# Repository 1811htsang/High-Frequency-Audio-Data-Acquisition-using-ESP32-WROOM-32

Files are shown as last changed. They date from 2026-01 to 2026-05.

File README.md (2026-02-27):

# High-Frequency-Audio-Data-Acquisition-using-ESP32-WROOM-32

## Introduction

Design and implementation of a high-frequency audio data acquisition system using the ESP32-WROOM-32 microcontroller. The project aims to capture and process audio signals in real-time, leveraging the capabilities of the ESP32 for efficient data handling and transmission for audio tasks such as recording and playback.

---

## Structure

- `docs/`: Documentation and design notes.
  - `notes/`: Development notes and considerations.
  - `references/`: Reference materials and datasheets.
- `project-architecture/`: Overview of the project architecture, containing main driver code structure.
- `project-kicadspace/`: KiCad design files for the PCB layout and schematic.
- `project-obsidianspace/`: Obsidian vault for project notes and documentation.

---

## Overview

This project focuses on the development of a high-frequency audio data acquisition system using the ESP32-WROOM-32 microcontroller. The system is designed to capture audio signals at high sampling rates, process the data in real-time, and transmit it for further analysis or storage. The project encompasses both hardware design, including PCB layout and component selection, and software development for efficient data handling and communication. Key features include:

- Real-time audio data acquisition and processing.
- Efficient data transmission using the ESP32's Wi-Fi, Bluetooth & external storage capabilities.
- Robust firmware design for reliable operation in various conditions.

---

## Features

- **Microcontroller**: ESP32-S3-DevKitC N16R8 for high-performance processing and connectivity.
- **Peripherals**:
  - SPI for communication with external microSD card for data storage
  - I2S for audio data acquisition from the ADC
  - GPIO for status indicators and control signals
  - RCC for reset & clock management
  - IWDG for watchdog functionality
  - I2C for LCD interfacing (optional)
  - DMA for efficient data transfer from ADC to memory

---

## Hardware Components

Note that this sections can be expand with new requirements in the future.

- ESP32-WROOM-32 microcontroller
- MAX9812 microphone amplifier
- PCM1808 ADC
- TL072IDT operational amplifier
- MicroSD card module for data storage
- Optional: I2C LCD display for status monitoring

---

## References

- Audio Data Acquisition System Design Based on ARM and DSP by Yongxin Wang, 2015.

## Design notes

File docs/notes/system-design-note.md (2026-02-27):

# Ghi chú về thiết kế hệ thống

## Giới thiệu

Ghi chú này tổng hợp các thiết kế hệ thống của dự án nhằm đảm bảo hoạt động ổn định và hiệu quả.

## Ý tưởng thiết kế

Thiết kế sử dụng sẽ lấy ý tưởng từ tài liệu [paper](../references/audio-data-acquisition-system-design-based-on-arm-and-dsp.pdf) nhằm đảm bảo tính ổn định và hiệu quả của hệ thống đã được kiểm chứng.

Đối với thiết kế hệ thống của tài liệu, nhóm tác giả sử dụng kết hợp giữa 1 vi điều khiển ARM với 1 DSP để xử lý âm thanh phức tạp.

Do đó, một câu hỏi đặt ra là ta có thể sử dụng một vi điều khiển duy nhất với 1 bộ thu thập dữ liệu sử dụng MAX9812, PCM1808, TL072IDT để thay thế cho thiết kế ban đầu hay không?

## Thay đổi thiết kế tương ứng

Từ thiết kế ban đầu, đã có một số thay đổi để phù hợp với yêu cầu của dự án:

- Thay thế cấu trúc thiết kế hệ thống của bài báo bằng một thiết kế mới sử dụng ESP32-S3-DevKitC N16R8 làm vi điều khiển chính, kết hợp với các bộ thu thập dữ liệu như MAX9812, PCM1808, TL072IDT để xử lý âm thanh.
- Vận dụng các giao thức như SPI, I2S, GPIO, RCC, IWDG, I2C và DMA để đảm bảo hiệu quả trong việc thu thập và xử lý dữ liệu âm thanh tương tự (96kHz/24-bit) như trong thiết kế ban đầu.

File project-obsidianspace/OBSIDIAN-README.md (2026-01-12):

# High-Frequency-Audio-Data-Acquisition-using-ESP32-WROOM-32
This README is a sub-artifact served as an inner README or artifactspace of the main project (parent folder).

## obsidianspace contents
The obsidianspace of the project **High-Frequency-Audio-Data-Acquisition-using-ESP32-WROOM-32** contains input sources from [docs](/docs/) of the main project.

Below is short explanation of the folder structure in the obsidianspace.

```
├── references
```

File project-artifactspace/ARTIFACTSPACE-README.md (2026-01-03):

# High-Frequency Audio Data Acquisition using ESP32-WROOM-32
This README is a sub-artifact served as an inner README or artifactspace of the main project (parent folder).

## artifactspace contents
The artifactspace of the project **High-Frequency Audio Data Acquisition using ESP32-WROOM-32** contains one source file in C language [main.c](main/main.c). The file is located in folder [main](main).

ESP-IDF projects are built using CMake. The project build configuration is contained in `CMakeLists.txt` files that provide set of directives and instructions describing the project's source files and targets (executable, library, or both). 
Below is short explanation of remaining files in the project folder.

```
├── CMakeLists.txt
├── main
│   ├── CMakeLists.txt
│   └── main.c
└── README.md                  This is the file you are currently reading
```
Additionally, the sample project contains Makefile and component.mk files, used for the legacy Make based build system. 
They are not used or needed when building with CMake and idf.py.

## Additional information
The ESP32-WROOM-32 is in fact the ESP32-DOWDQ6 denoted on [ESP32 Series Datasheet](docs\references\esp32-series-datasheet-ver-4_7.pdf)

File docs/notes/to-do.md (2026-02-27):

# To do List

## Ghi chú

Lộ trình triển khai chi tiết, đi từ

  1. **Cốt lõi** (Hardware interface & I2S Driver)
  2. **Kiến trúc** (Dual-core & Memory Management)
  3. **DSP** (Digital Signal Processing)
  4. **Giao tiếp dữ liệu** (Connectivity & Data Visualization)
  5. **Kiểm chứng và tối ưu** (Validation & Optimization)

## Giai đoạn Cốt lõi

- [x] Thiết kế khung dự án (Project Structure)
- [x] Bổ sung các tài liệu căn bản của dự án
- [x] Tìm hiểu về thiết kế reset và clock nội bộ của ESP32
- [x] Viết driver setup clock cho ESP32 lên tối đa 240MHz
- [x] Tìm hiểu về I2S Protocol và cách hoạt động của I2S trên ESP32
- [x] Tìm hiểu các linh kiện phần cứng hỗ trợ thiết kế
- [x] Tìm hiểu về SPI Protocol và cách hoạt động của SPI trên ESP32
- [x] Tái cấu trúc và thay đổi cách tận dụng driver từ ESP-IDF thay thế cho bare-metal driver
- [x] Mua linh kiện phần cứng cần thiết cho việc phát triển và thử nghiệm

## Giai đoạn Kiến trúc

## Giai đoạn DSP

## Giai đoạn Giao tiếp dữ liệu

## Giai đoạn Kiểm chứng và tối ưu

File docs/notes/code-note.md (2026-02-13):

# Ghi chú khi viết driver cho ESP32

## Các lưu ý quan trọng

1. Trước khi viết driver nên tìm hiểu bổ sung về vấn đề Big/Little Endian trên ESP32. Nếu không xác định đúng sẽ rất dễ gặp lỗi khi xử lý dữ liệu nhị phân hoặc trong quá trình cài đặt thanh ghi hoặc set/reset các bit trên thanh ghi sẽ bị sai lệch.
2. Nên thiết kế driver theo 3 lớp, trong đó:

   - Lớp thấp nhất: Giao tiếp trực tiếp với phần cứng (thanh ghi, bus giao tiếp,...)
   - Lớp trung gian: Xử lý các logic nghiệp vụ, chuyển đổi dữ liệu giữa lớp thấp và lớp cao.
   - Lớp cao nhất: Cung cấp API cho ứng dụng sử dụng driver.

    Phương pháp này giúp tách biệt rõ ràng các chức năng, dễ dàng bảo trì và mở rộng trong tương lai. Ngoài ra, hỗ trợ kiểm tra unit test cho từng lớp riêng biệt.

3. Sử dụng các macro và định nghĩa trong file lib_keyword_define.h để đảm bảo tính nhất quán và dễ bảo trì mã nguồn.

## Ghi chú ngày 12-2-2026

Dựa trên các đánh giá về việc khai thác hướng xây dựng driver bare-metal cho ESP32, đối với dự án này sẽ thực hiện việc sử dụng ESP-IDF framework để tận dụng các thư viện và công cụ hỗ trợ sẵn có. Điều này giúp giảm thiểu thời gian phát triển và tăng tính ổn định của hệ thống.

Nguyên nhân được đưa ra như sau:

- Kiến trúc của ESP32 theo hướng SoC với nhiều thành phần tích hợp sẵn, việc viết driver từ đầu sẽ rất phức tạp và dễ gặp lỗi so với STM32 là 1 MCU.
- ESP-IDF cung cấp nhiều driver và thư viện đã được tối ưu hóa, giúp tiết kiệm thời gian phát triển.
- Việc sử dụng ESP-IDF giúp tận dụng cộng đồng hỗ trợ rộng lớn và tài liệu phong phú, giúp giải quyết các vấn đề nhanh hơn.

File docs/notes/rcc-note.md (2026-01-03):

# Reset
Chia ra làm 3 loại:
- CPU reset
- Core reset
- System reset

## CPU reset
Chỉ thực hiện reset các reg của lõi CPU

## Core reset
Thực hiện reset tất cả thanh ghi trừ nhóm thanh ghi RTC

## System reset
Thực hiện reset tất cả thanh ghi (kể cả nhóm thanh ghi RTC) về giá trị mặc định.

### Nhận xét
System reset là loại reset cao nhất, do đó việc lựa chọn reset cần phải cân nhắc kỹ lưỡng để tránh việc reset không cần thiết. Ngoài ra, tất cả các loại reset đều không ảnh hưởng đến RAM. 

## Nguồn reset
Do CPU chia ra APP_CPU và PRO_CPU nên có 2 nguồn reset riêng biệt:
- Nguồn reset của PRO_CPU trữ trong thanh ghi `RTC_CNTL_RESET_CAUSE_PROCPU`
- Nguồn reset của APP_CPU trữ trong thanh ghi `RTC_CNTL_RESET_CAUSE_APPCPU`

Bảng tra cứu reset có trong [tech-dts](/docs/references/esp32-technical-reference-manual-ver-5_2.pdf) trang 40

## Quy trình reset sử dụng Software reset
1. `RTC_CNTL_OPTIONS0_REG->RTC_CNTL_SW_SYS_RST = 1;` // System reset

Do việc reset này bổ sung thêm việc lựa chọn cụ thể CPU cho việc reset:
- Với APP_CPU, `RTC_CNTL_RESET_STATE_REG->RTC_CNTL_RESET_CAUSE_APPCPU = 0x03;` // Software reset applies System reset to APP CPU
- Với PRO_CPU, `RTC_CNTL_RESET_STATE_REG->RTC_CNTL_RESET_CAUSE_PROCPU = 0x03;` // Software reset applies System reset to PRO CPU

## Quy trình reset sử dụng CPU reset
Đối với CPU reset, chỉ có thể reset từng CPU riêng biệt

Với APP_CPU:
1. `RTC_CNTL_OPTIONS0_REG->RTC_CNTL_SW_APPCPU_RST = 1;` // CPU reset với APP CPU
2. Với APP_CPU, `RTC_CNTL_RESET_STATE_REG->RTC_CNTL_RESET_CAUSE_APPCPU = 0x0C;` // Software reset applies System reset to APP CPU

Với PRO_CPU:
1. `RTC_CNTL_OPTIONS0_REG->RTC_CNTL_SW_PROCPU_RST = 1;` // CPU reset với PRO CPU
2. Với PRO_CPU, `RTC_CNTL_RESET_STATE_REG->RTC_CNTL_RESET_CAUSE_PROCPU = 0x0C;` // Software reset applies System reset to PRO CPU

## Trường hợp đặc biệt
Do APP_CPU được điều khiển bổ sung bởi nhóm thanh ghi DPort (PRO_CPU khong có), do đó việc reset APP_CPU có thể thực hiện thông qua DPort (`DPORT_APPCPU_CTRL_REG_A_REG->DPORT_APPCPU_RESETTING = 1;`)

Tuy nhiên cách thực hiện reset chỉ xảy ra với nguồn đầu vào là tín hiệu reset độc lập của PRO_CPU.

Kiểm chứng thông tin trong [tech-dts](/docs/references/esp32-technical-reference-manual-ver-5_2.pdf) trang 40, 41

# Clock system trên ESP32-WROOM-32
Về thiết kế cơ bản, ESP32-WROOM-32 gồm các nguồn chính sau:
- CLK tốc độ cao
  - `PLL_CLK` là clk nội bộ với dải tần số từ 320MHz đến 480MHz
  - `XTL_CLK` là clk từ thạch anh ngoài với tần số 2-40MHz
- CLK tốc độ thấp
  - `XTL32K_CLK` là clk từ thạch anh ngoài với tần số 32kHz 
  - `RC_FAST_CLK` là nguồn clock nội với tần số mặc định 8MHz có thể tùy chỉnh
  - `RC_FAST_DIV_CLK` là nguồn tách từ `RC_FAST_CLK` với phần chia 256. Do đó với tần số mặc định 8MHz thì `RC_FAST_DIV_CLK` có tần số 31.25kHz
  - `RC_SLOW_CLK` là nguồn clock nội với tần số mặc định 150kHz có thể tùy chỉnh
- CLK cho Audio
  - `APLL_CLK` là clock nội bộ dành riêng cho Audio với tần số từ 16MHz đến 128MHz

Kiểm tra nguồn thông tin trong [tech-dts](/docs/references/esp32-technical-reference-manual-ver-5_2.pdf) trang 41 đối với phần cấu trúc thiết kế hệ thống clock trên ESP32-WROOM-32

## Nguồn clock cho CPU

Ngoài các nguồn clock trên, CPU còn có nguồn clock riêng biệt là `CPU_CLK` sử dụng riêng biệt cho lõi CPU. Ở chế độ hiệu năng cao, `CPU_CLK` có thể đạt tần số tối đa 240MHz.

Việc lựa chọn nguồn clock cho `CPU_CLK` được xác định bởi thanh ghi `RTC_CNTL_SOC_CLK_SEL`. Trong đó `PLL_CLK`, `APLL_CLK`, `RC_FAST_CLK` và  `XTL_CLK` đều có thể được lựa chọn làm nguồn cho `CPU_CLK`.

Kiểm chứng thông tin trong [tech-dts](/docs/references/esp32-technical-reference-manual-ver-5_2.pdf) trang 42-43.

## Nguồn clock cho ngoại vi
Nguồn clock cho tất cả các ngoại vi được lấy đầu vào từ 5 nguồn chính là
- `APB_CLK`
- `REF_TICK`
- `LEDC_SCLK`
- `APLL_CLK`
- `PLL_F160M_CLK`

Ngoài ra, tùy thuộc vào từng ngoại vi cụ thể mà có thể sử dụng các nguồn CLK khác nhau, điều này được ghi chú kỹ trong phần mô tả [tech-dts](/docs/references/esp32-technical-reference-manual-ver-5_2.pdf) từ trang 43.

Lưu ý ở đây chỉ tập trung vào các nguồn clock chính, các nguồn clock không sử dụng trong dự án sẽ không được đề cập.

### `APB_CLK`
Nguồn này lấy từ 4 nguồn chính là `PLL_CLK`, `APLL_CLK`, `XTL_CLK` và `RC_FAST_CLK`.

Bảng thông số chia nguồn `APB_CLK` có trong [tech-dts](/docs/references/esp32-technical-reference-manual-ver-5_2.pdf) trang 43.

### `REF_TICK`
Nguồn này phụ thuộc vào `APB_CLK` mà `APB_CLK` được xác định bởi `CPU_CLK`.

Trong tài liệu, nguồn này được khuyến khích đảm bảo cố định (không ràng buộc tần số ở 1MHz). Nghĩa là khi thay đổi `CPU_CLK` thì người sử dụng nên đảm bảo nguồn `REF_TICK` vẫn giữ nguyên tần số mong muốn.

Bảng thông tin nằm trong [tech-dts](/docs/references/esp32-technical-reference-manual-ver-5_2.pdf) trang 44.

Giải thích ví dụ ở trang 44:
> Khi nguồn `CPU_CLK` là `PLL_CLK` và người dùng cần giữ `REF_TICK` ở 1MHz thì phải đảm bảo `SYSCON_PLL_TICK_NUM=0x4F` để tần số `REF_TICK` tương đương `80/(79+1)=1` (Thông tin về công thức nằm chung với bảng ở trang 44).

### `APLL_CLK` cho ngoại vi
Như đã đề cập trước đó, `APLL_CLK` là nguồn clock nội bộ dành riêng cho Audio với tần số từ 16MHz đến 128MHz.

Nguồn đầu vào chính của `APLL_CLK` là từ `PLL_CLK`, do đó phải sử dụng bổ sung các nhóm thanh ghi để điều chỉnh tần số của `APLL_CLK`. 

Tuy nhiên, trong tài liệu không đề cập rõ ràng thông tin về điều chỉnh trực tiếp tần số của `APLL_CLK` mà chỉ xem `APLL_CLK` là nguồn con phụ thuộc vào `PLL_CLK`.

Ngoài ra còn có 1 phần đề mục *Audio PLL* riêng biệt khỏi `APLL_CLK` trong tài liệu và thông tin cụ thể chi tiết hơn.

Do đó, có thể suy đoán rằng việc điều chỉnh tần số của `APLL_CLK` sẽ thông qua việc điều chỉnh tần số của `PLL_CLK`.

Kiểm chứng thông tin trong [tech-dts](/docs/references/esp32-technical-reference-manual-ver-5_2.pdf) trang 44.

### `PLL_F160M_CLK`
Nguồn này lấy trực tiếp từ `PLL_CLK` với tần số cố định 160MHz không thay đổi.

## Cân nhắc lựa chọn clock đối với ngoại vi
Trong tài liệu về bảng thông tin nguồn clock cho các loại ngoại vii, ta có thể thấy rằng tất cả ngoại vi đều có thể sử dụng `APB_CLK` làm nguồn clock chính. 

Ngoài ra nếu tần số của `APB_CLK` bị thay đổi thì các ngoại vi cũng đều phải thực hiện cập nhật lại tần số hoạt động tương ứng trừ các ngoại vi có thể sử dụng `REF_TICK` làm nguồn clock.

## Nguồn clock cho Wi-Fi và Bluetooth
Sử dụng bắt buộc nguồn clock chính là `PLL_CLK`. Nếu không sử dụng `PLL_CLK` thì cả 2 chức năng này sẽ tiến vào trạng thái hoạt động tiêu thụ thấp (low-power mode).

Nếu sử dụng trong chế độ tiết kiệm năng lượng (modem-sleep mode) thì có thể sử dụng các nguồn clock phụ là `RC_SLOW_CLK`, `RC_FAST_CLK` hoặc `XTL_CLK`.

Kiểm chứng thông tin trong [tech-dts](/docs/references/esp32-technical-reference-manual-ver-5_2.pdf) trang 45.

## Nguồn clock cho RTC
Trong thiết kế hệ thống clock của ESP32, RTC có 2 nguồn chính là `RTC_SLOW_CLK` và `RTC_FAST_CLK`, 2 nguồn này giúp cho RTC có thể hoạt động khi hầu hết các nguồn khác bị tắt.

Dựa vào thiết kế truy ngược lại, ta có thể thấy:

### RTC_FAST_CLK
Nguồn này lấy từ 2 nguồn chính là
- `RC_FAST_CLK`
- `XTL_CLK` + Bộ chia tần số -> `XTAL_DIV_CLK`

Nguồn này có thể sử dụng cho các module quản lý năng lượng.

### RTC_SLOW_CLK
Nguồn này lấy từ 3 nguồn chính là
- `RC_SLOW_CLK`
- `XTL32K_CLK`
- `RC_FAST_DIV_CLK`

Nguồn này có thể sử dụng cho các module cảm biến trên chip.

Kiểm chứng thông tin trong [tech-dts](/docs/references/esp32-technical-reference-manual-ver-5_2.pdf) trang 45.

## Nguồn clock cho Audio PLL
Công thức tính nguồn clock ra từ Audio PLL như sau:
$$\large{f_{\text{out}}=\frac{f_{\text{xtal}}(\text{sdm2}+\frac{\text{sdm1}}{2^{8}}+\frac{\text{sdm0}}{2^{16}}+4)}{2(\text{odiv}+2)}}$$

Trong đó:
- \(f_{xtal}\) là tần số của thạch anh ngoài (thường là 40MHz)
- sdm2, sdm1, sdm0 là các hệ số điều chỉnh tần số
  - sdm2 là phần nguyên lấy giá trị từ 0 đến 63
  - sdm1 là phần phân số lấy giá trị từ 0 đến 255
  - sdm0 là phần phân số lấy giá trị từ 0 đến 255
- odiv là hệ số chia tần số đầu ra, giá trị từ 0 đến 31

Với công thức này, toán hạng tử số có thể đạt từ 350MHz đến 500MHz.

Ngoài ra, cần chú ý rằng ở revision0 của ESP32, không thể setup `smd0` và `smd1`, kiểm chứng thông tin trong [soc-errata](../references/esp32-eco-&-workarounds-for-bugs-ver-2_3.pdf) trang 12.

Audio PLL có thể được điều khiển thủ công qua thanh ghi `RTC_CNTL_PLLA_FORCE_PU` và `RTC_CNTL_PLLA _FORCE_PD` tương ứng. Quyền vô hiệu hóa có mức ưu tiên cao hơn so với quyền kích hoạt. Nếu cả 2 thanh ghi đều là 0 thì Audio PLL sẽ tuân thủ theo trạng thái hoạt động của hệ thống.

## Quy trình setup Clock cho ESP32
Dựa trên các nguồn thông tin đã thu thập, các hạng mục chính cần setup clock bao gồm `CPU_CLK`, `REF_TICK`.

### Setup `CPU_CLK`
1. Chọn nguồn clock cho CPU trong `RTC_CNTL_SOC_CLK_SEL`. Ở đây chọn `PLL_CLK` làm nguồn chính cho CPU (Lý giải bên dưới) 
2. `RTC_CNTL_CLK_CONF_REG->RTC_CNTL_SOC_CLK_SEL=01`; // Chọn PLL_CLK làm nguồn cho CPU_CLK
3. `DPORT_CPU_PER_CONF_REG->DPORT_CPU_CPUPERIOD_SEL=10`; // Chọn tần số CPU là 240MHz

**Lý giải**:

Ở đây chọn `PLL_CLK` làm nguồn cho CPU vì
- Lấy mẫu ở tốc độ 100ksps có nghĩa là cứ 10µs hệ thống lại nhận được một mẫu dữ liệu mới. Mặc dù DMA giúp chuyển dữ liệu vào RAM mà không tốn CPU, nhưng sau đó Core 1 phải xử lý khối dữ liệu khổng lồ này (FFT, Filtering) và Core 0 phải duy trì Wifi Stack.
- Do đó, để đảm bảo hệ thống xử lý kịp thời gian thực, cần thiết lập CPU ở tần số cao nhất là 240MHz. Các nguồn khác như `XTL_CLK` hay `RC_FAST_CLK` không thể đáp ứng được tần số này.
- Ngoài ra loại bỏ việc sử dụng `APLL_CLK` làm nguồn cho CPU vì nguồn này dành riêng cho Audio, việc sử dụng nó cho CPU như đã đề cập sẽ làm gián đoạn chức năng Audio trong trường hợp tần số `APLL_CLK` bị thay đổi.

### Setup `REF_TICK`
1. Xác định tần số mong muốn cho REF_TICK (Ở đây chọn 1MHz)
2. `SYSCON_PLL_TICK_CONF_REG->SYSCON_PLL_TICK_NUM=0x4F`; // Thiết lập tần số REF_TICK là 1MHz khi CPU_CLK là PLL_CLK

> Ở đây sẽ bổ sung thêm phần setup clock cho các ngoại vi nếu cần thiết trong tương lai.

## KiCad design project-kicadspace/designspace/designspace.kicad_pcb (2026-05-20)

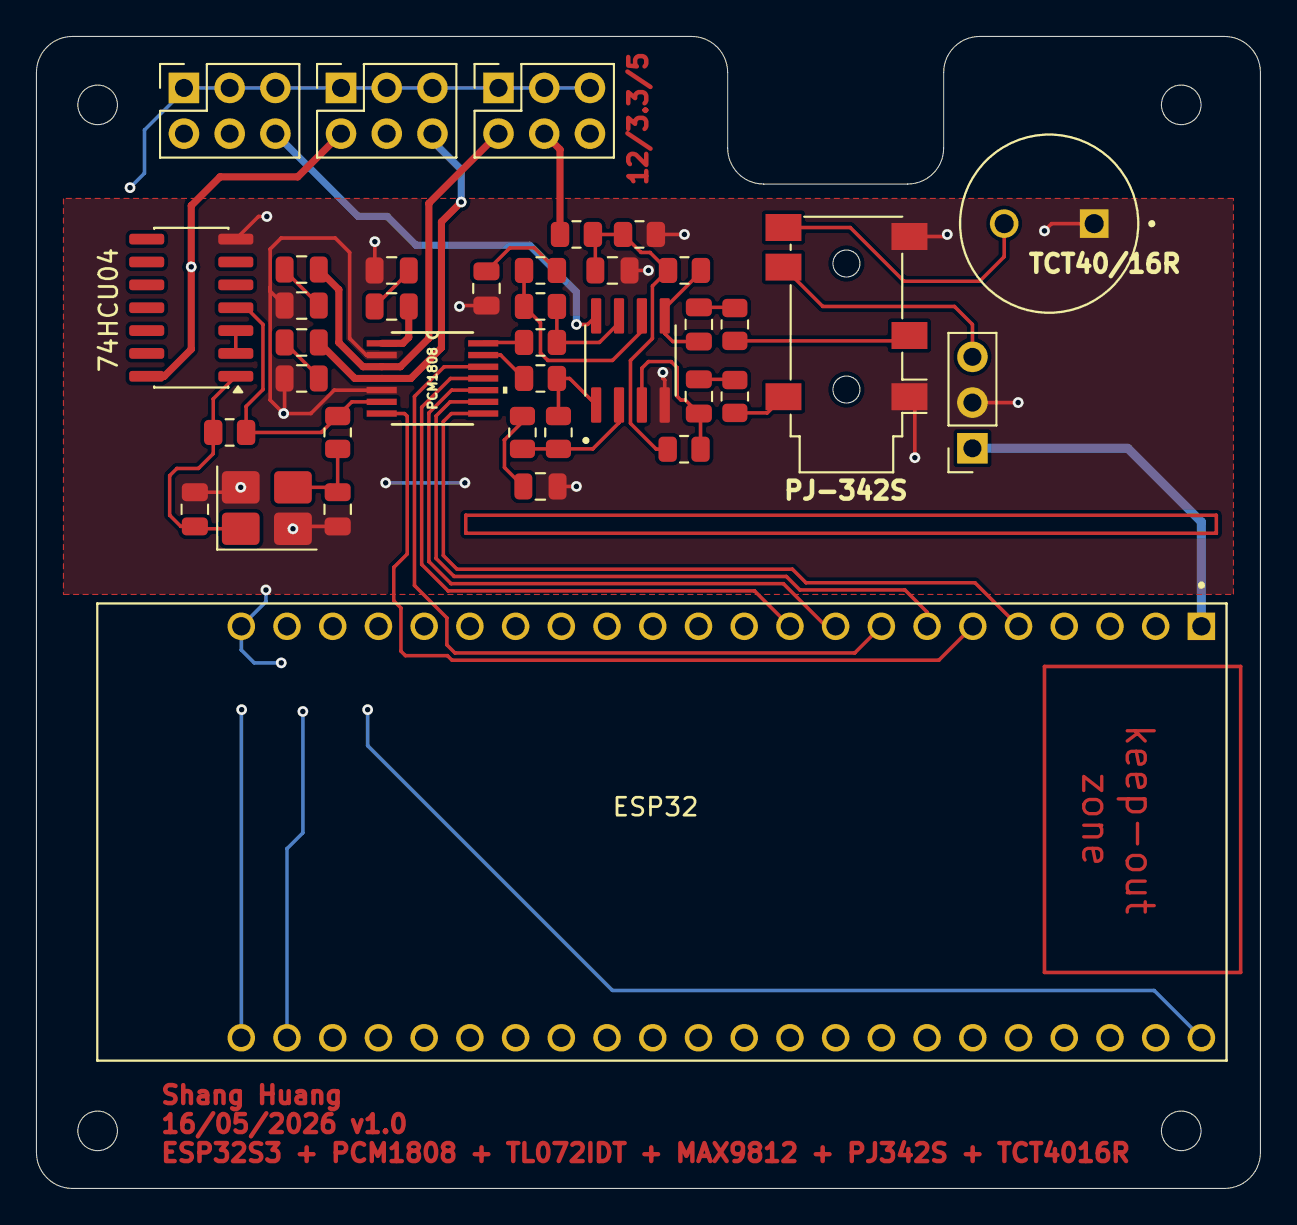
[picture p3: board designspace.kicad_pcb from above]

Board: 2 copper layers, 68.0 x 64.0 mm, 34 parts (0 on the bottom side), 33 nets.

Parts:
C3, C15: 1uF; C_0805_2012Metric
C4, C6, C8, C10, C13, C14: 10uF; C_0805_2012Metric
C5, C7, C9: 0.1uF; C_0805_2012Metric
C11, C12: 27pF; C_0805_2012Metric
ESP32: ESP32-S3-DEVKITC-1-N8R8
INVBUF1: 74HCU04; SO-14_3.9x8.65mm_P1.27mm
J1: PJ-313B; pj342s audio jack
MK2: TCT40-16R
Op-amp2: TL072; TL072IDT
Osc1: 24.576MHz; Crystal_SMD_3225-4Pin_3.2x2.5mm_HandSoldering
PCM1808: PCM1808PWR; PW14
R2, R3, R4, R10, R11: 10kOhm; R_0805_2012Metric
R5, R6, R9, R15: 1kOhm; R_0805_2012Metric
R7, R13: 100kOhm; R_0805_2012Metric
R8, R12: 1MOhm; R_0805_2012Metric
R14: 2.2kOhm; R_0805_2012Metric

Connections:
3.3V: C8.1, ESP32.3V3, INVBUF1.14 (VCC), PCM1808.4 (VDD)
5V: C4.1, PCM1808.3 (VCC), R2.1
GND: C5.1, C6.2, C9.1, C10.1, C11.2, C12.2, C13.1, C14.1, ESP32.GND, ESP32.GND1, ESP32.GND2, ESP32.GND3, INVBUF1.7 (GND), J1.G, J1.S, MK2.1 (-), Op-amp2.4 (V-), Osc1.2 (G), Osc1.4 (G), PCM1808.2 (AGND), PCM1808.5 (DGND), R3.2
unnamed: C3.2, R10.1
unnamed: C4.2, C5.2
unnamed: C6.1, C7.1
unnamed: C8.2, C9.2
unnamed: C10.2, R5.1
unnamed: C11.1, INVBUF1.1, Osc1.1, R8.1
unnamed: C12.1, Osc1.3, R9.1
unnamed: C13.2, R2.2, R3.1, R7.1, R12.2
unnamed: C14.2, R14.1
unnamed: C15.2, R11.1
unnamed: INVBUF1.2, INVBUF1.3
unnamed: J1.R1, R11.2
unnamed: J1.T, R10.2
unnamed: J1.R2, MK2.2 (+)
unnamed: Op-amp2.1, R4.1, R6.1
unnamed: Op-amp2.7, R13.1, R15.2
unnamed: C3.1, Op-amp2.3 (+), R7.2
unnamed: Op-amp2.2 (-), R4.2, R5.2
unnamed: C15.1, Op-amp2.5 (+), R12.1
unnamed: Op-amp2.6 (-), R13.2, R14.2
unnamed: ESP32.GPIO5, PCM1808.8 (BCK)
unnamed: ESP32.GPIO7, PCM1808.9 (DOUT)
unnamed: ESP32.GPIO15, PCM1808.12 (FMT)
unnamed: ESP32.GPIO6, PCM1808.7 (LRCK)
unnamed: ESP32.GPIO16, PCM1808.10 (MD0)
unnamed: ESP32.GPIO17, PCM1808.11 (MD1)
unnamed: INVBUF1.4, PCM1808.6 (SCKI), R8.2, R9.2
unnamed: PCM1808.13 (VINL), R6.2
unnamed: PCM1808.14 (VINR), R15.1
unnamed: C7.2, PCM1808.1 (VREF)

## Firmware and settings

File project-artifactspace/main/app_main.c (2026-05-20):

// Khai báo các thư viện sử dụng

  #include <stdio.h>
  #include <stdint.h>
  #include <inttypes.h>
  #include "esp_system.h"
  #include "soc/clk_tree_defs.h"
  #include "esp_clk_tree.h"
  #include "esp_pm.h"
  #include "esp_log.h"
  #include "freertos/FreeRTOS.h"
  #include "freertos/task.h"
  #include "driver/i2s_std.h"
  #include "driver/i2s_common.h"
  #include "driver/gpio.h"
  #include "lib_keyword_def.h"
  #include "lib_condition_def.h"

// Khai báo các hằng số và biến toàn cục nếu cần thiết

  #define LOG_LOCAL_LEVEL ESP_LOG_VERBOSE

  #define ui32 uint32_t
  #define ui16 uint16_t
  #define ui8 uint8_t

  #define I2S_SAMPLE_RATE_HZ 96000
  #define I2S_RX_BUFFER_SAMPLES 512
  #define I2S_LOG_SAMPLES_PER_CHUNK 8

// Khai báo các hàm sử dụng làm việc

  void check_reset_reason(void);
  void check_cpu_clock(void);

// Thực thi chương trình chính

  void app_main(void) {

    // Kiểm tra nguyên nhân khởi động
      
      check_reset_reason();

    // Kiểm tra xung clock nội bộ

      check_cpu_clock();

    // Cấu hình quản lý năng lượng

      /**
       * Ghi chú:
       * Đã sử dụng cấu hình năng lượng thông qua
       * `menuconfig` nên không cần dùng API để cấu hình lại ở đây
       */

    // Cấu hình I2S

      // Khởi tạo I2S channel
      i2s_chan_handle_t rx_handle;
      i2s_chan_config_t chan_cfg = I2S_CHANNEL_DEFAULT_CONFIG(I2S_NUM_0, I2S_ROLE_MASTER);
      chan_cfg.dma_desc_num = I2S_LOG_SAMPLES_PER_CHUNK;
      chan_cfg.dma_frame_num = I2S_RX_BUFFER_SAMPLES;
      ESP_ERROR_CHECK(i2s_new_channel(&chan_cfg, NULL, &rx_handle));

      // Cấu hình I2S định dạng chuẩn
      /**
       * Ghi chú:
       * Theo tài liệu Series datasheet của S3,
       * thì I2S được quyền sử dụng các chân từ GPIO4 đến GPIO7 cho chức năng I2S, 
       * ngoài ra trên thực tế, các chân này liền kề nhau 
       * cũng giúp việc routing tín hiệu dễ dàng hơn trên phần cứng,
       * do đó ta sẽ chọn các chân này để kết nối với PCM1808.
       * Cấu hình này sử dụng thạch anh rời để làm nguồn clock,
       * tuy nhiên do linh kiện chưa về kịp nên tạm thời sử dụng clock PLL nội bộ để test
       */
      
      /*
      i2s_std_config_t std_cfg = {
        .clk_cfg = {
          .sample_rate_hz = 96000,
          .clk_src = I2S_CLK_SRC_EXTERNAL,
          .mclk_multiple = I2S_MCLK_MULTIPLE_256,
          .ext_clk_freq_hz = 24576000,
        },
        .slot_cfg = I2S_STD_MSB_SLOT_DEFAULT_CONFIG(I2S_DATA_BIT_WIDTH_32BIT, I2S_SLOT_MODE_STEREO),
        .gpio_cfg = {
          .mclk = GPIO_NUM_4, // Master clock (MCLK) được cung cấp từ nguồn clock ngoài 24.576MHz
          .bclk = GPIO_NUM_5, // Bit clock (BCLK) sẽ được tạo ra dựa trên MCLK, tần số sẽ là 6.144MHz (24.576MHz / 4)
          .ws = GPIO_NUM_6, // Word select (WS/LRCK) sẽ được tạo ra dựa trên BCLK, tần số sẽ là 96kHz (6.144MHz / 64, với 32-bit slot và stereo)
          .dout = I2S_GPIO_UNUSED, // Có thể sử dụng trong trường hợp mở rộng chức năng
          .din = GPIO_NUM_7,
          .invert_flags = {
              .mclk_inv = false,
              .bclk_inv = false,
              .ws_inv = false,
          },
        },
      };
      */

      i2s_std_config_t std_cfg = {
        .clk_cfg = {
          .sample_rate_hz = I2S_SAMPLE_RATE_HZ,
          .clk_src = I2S_CLK_SRC_DEFAULT, // Tạm thời sử dụng clock PLL nội bộ để test
          .mclk_multiple = I2S_MCLK_MULTIPLE_256,
          .ext_clk_freq_hz = 24576000, // Tần số của thạch anh rời dự kiến sẽ sử dụng, chỉ mang tính chất tham khảo khi test với clock nội bộ
        },
        .slot_cfg = I2S_STD_MSB_SLOT_DEFAULT_CONFIG(I2S_DATA_BIT_WIDTH_32BIT, I2S_SLOT_MODE_STEREO),
        .gpio_cfg = {
          .mclk = GPIO_NUM_4, // Master clock (MCLK) được cung cấp từ nguồn clock ngoài 24.576MHz
          .bclk = GPIO_NUM_5, // Bit clock (BCLK) sẽ được tạo ra dựa trên MCLK, tần số sẽ là 6.144MHz (24.576MHz / 4)
          .ws = GPIO_NUM_6, // Word select (WS/LRCK) sẽ được tạo ra dựa trên BCLK, tần số sẽ là 96kHz (6.144MHz / 64, với 32-bit slot và stereo)
          .dout = I2S_GPIO_UNUSED, // Có thể sử dụng trong trường hợp mở rộng chức năng
          .din = GPIO_NUM_7,
          .invert_flags = {
              .mclk_inv = false,
              .bclk_inv = false,
              .ws_inv = false,
          },
        },
      };
      ESP_ERROR_CHECK(i2s_channel_init_std_mode(rx_handle, &std_cfg));

      /**
       * Ghi chú:
       * Thiết kế đảm bảo theo tài liệu của PCM1808, ta sẽ đạt được
       * - Tốc độ lấy mẫu 96kHz (dùng trong đầu ra của pin WS/LRCK)
       * - Độ phân giải 24-bit (sử dụng 32-bit slot để chứa dữ liệu 24-bit theo định dạng MSB-first & Left-justified)
       * - Sử dụng nguồn clock ngoài 24.576MHz (được cung cấp qua pin MCLK) để đảm bảo độ chính xác của tốc độ lấy mẫu, 
       * tránh sai lệch do clock nội bộ có thể không ổn định hoặc bị ảnh hưởng bởi các yếu tố khác.
       * - BCK đạt tần số 6.144MHz (tính toán từ MCLK 24.576MHz chia cho 4, phù hợp với tốc độ lấy mẫu 96kHz và độ phân giải 24-bit)
       * - Cấu hình GPIO phù hợp với sơ đồ kết nối phần cứng đã thiết kế, đảm bảo tín hiệu được truyền đúng cách giữa ESP32 và PCM1808.
       */

      /**
       * Ghi chú:
       * Về phần truyền tải dữ liệu trong ESP32 đã được hỗ trợ cấu hình với DMA sẵn,
       * Do đó khi sử dụng API `i2s_channel_read()`, dữ liệu sẽ được tự động truyền qua DMA mà không cần phải cấu hình thêm gì cả,
       * Điều này giúp giảm tải cho CPU và tăng hiệu suất truyền dữ liệu.
       */


      // Cấp phát buffer nhận mẫu âm thanh và bắt đầu đọc liên tục
      int32_t *rx_buffer = (int32_t *)heap_caps_malloc(sizeof(int32_t) * I2S_RX_BUFFER_SAMPLES, MALLOC_CAP_DMA | MALLOC_CAP_INTERNAL);
      if (rx_buffer == NULL) {
          ESP_LOGE("main", "Failed to allocate RX buffer");
          return;
      }
      size_t bytes_read = 0;

      ESP_ERROR_CHECK(i2s_channel_enable(rx_handle));
      ESP_LOGI("main", "I2S RX started: sample_rate=%d Hz, dma_desc_num=%d, dma_frame_num=%d",
        I2S_SAMPLE_RATE_HZ,
        chan_cfg.dma_desc_num,
        chan_cfg.dma_frame_num
      );

      while (1) {

        // delay một khoảng thời gian để tránh log quá nhiều, đồng thời cũng giúp dễ quan sát hơn
        vTaskDelay(pdMS_TO_TICKS(100));

        esp_err_t read_err = i2s_channel_read(
          rx_handle,
          rx_buffer,
          sizeof(rx_buffer),
          &bytes_read,
          pdMS_TO_TICKS(1000)
        );

        if (read_err == ESP_OK && bytes_read > 0) {
          size_t samples_read = bytes_read / sizeof(rx_buffer[0]);
          size_t samples_to_log = (samples_read < I2S_LOG_SAMPLES_PER_CHUNK) ? samples_read : I2S_LOG_SAMPLES_PER_CHUNK;

          ESP_LOGI("main", "RX bytes=%u, samples=%u", (unsigned int)bytes_read, (unsigned int)samples_read);

          for (size_t i = 0; i < samples_to_log; i++) {
            // PCM1808 xuất 24-bit, dữ liệu đặt trong slot 32-bit nên dịch phải 8-bit để xem biên độ signed 24-bit.
            int32_t sample_24 = (rx_buffer[i] >> 8);
            ESP_LOGI("main", "sample[%u] raw=0x%08" PRIx32 " s24=%" PRId32,
              (unsigned int)i,
              (uint32_t)rx_buffer[i],
              sample_24
            );
          }
        }
        else if (read_err == ESP_ERR_TIMEOUT) {
          ESP_LOGW("main", "I2S read timeout: khong nhan duoc du lieu trong 1000 ms");
        }
        else {
          ESP_LOGE("main", "I2S read error: %s", esp_err_to_name(read_err));
          vTaskDelay(pdMS_TO_TICKS(100));
        }
      }
  }

  void check_reset_reason(void) {
    esp_reset_reason_t reset_reason = esp_reset_reason();
    ESP_LOGI("main", "Reset reason: %d", reset_reason);

    switch (reset_reason) {
      case ESP_RST_UNKNOWN:
        ESP_LOGI("main", "Unknown reset reason.");
        break;
      case ESP_RST_POWERON:
        ESP_LOGI("main", "Power-on reset detected.");
        break;
      case ESP_RST_EXT:
        ESP_LOGI("main", "External pin reset detected.");
        break;
      case ESP_RST_SW:
        ESP_LOGI("main", "Software reset detected.");
        break;
      case ESP_RST_PANIC:
        ESP_LOGI("main", "Software reset due to exception/panic detected.");
        break;
      case ESP_RST_INT_WDT:
        ESP_LOGI("main", "Interrupt watchdog reset detected.");
        break;
      case ESP_RST_TASK_WDT:
        ESP_LOGI("main", "Task watchdog reset detected.");
        break;
      case ESP_RST_WDT:
        ESP_LOGI("main", "Other watchdog reset detected.");
        break;
      case ESP_RST_DEEPSLEEP:
        ESP_LOGI("main", "Woke up from deep sleep.");
        break;
      case ESP_RST_BROWNOUT:
        ESP_LOGI("main", "Brownout reset detected.");
        break;
      case ESP_RST_SDIO:
        ESP_LOGI("main", "SDIO reset detected.");
        break;
      case ESP_RST_USB:
        ESP_LOGI("main", "USB peripheral reset detected.");
        break;
      case ESP_RST_JTAG:
        ESP_LOGI("main", "JTAG reset detected.");
        break;
      case ESP_RST_EFUSE:
        ESP_LOGI("main", "Efuse error reset detected.");
        break;
      case ESP_RST_PWR_GLITCH:
        ESP_LOGI("main", "Power glitch reset detected.");
        break;
      case ESP_RST_CPU_LOCKUP:
        ESP_LOGI("main", "CPU lock up reset detected.");
        break;
      default:
        ESP_LOGI("main", "Unhandled reset reason: %d", reset_reason);
        break;
    }
  }

  void check_cpu_clock(void) {
    ui32 cpu_freq_mhz = 0;
    ESP_ERROR_CHECK(esp_clk_tree_src_get_freq_hz(
      SOC_MOD_CLK_CPU, 
      ESP_CLK_TREE_SRC_FREQ_PRECISION_EXACT, 
      &cpu_freq_mhz)
    );
    ESP_LOGI("main", "CPU frequency: %u Hz (~%u MHz)", cpu_freq_mhz, cpu_freq_mhz / 1000000U);
  }

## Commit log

2025-12-30 docs(to-do, pin-cfg-img): add checkpoint for to-do and pin configurations of ESP32
2025-12-31 docs(rcc-note): add detailed documentation on reset types and procedures for ESP32
2026-01-02 docs(to-do): update task list with driver setup for clock and system reset
2026-01-02 docs(code-note): add initial documentation on Big/Little Endian considerations for ESP32 driver development
2026-01-03 docs(to-do): update task list for system reset driver and hardware structure research
2026-01-03 docs(i2s-note): add comprehensive overview and design details for I2S architecture in ESP32
2026-01-07 docs(i2s, spi, to-do, max9812, pcm1808): add small adjustment to i2s note, new item for to-do, refs for adc, mic component
2026-01-07 docs(spi-note): enhance SPI documentation with detailed explanations of CPOL, CPHA, and QSPI modes
2026-01-08 docs(spi-note, to-do): add hardware interrupt support details and update task completion status
2026-01-12 docs(wdt-note): add comprehensive overview and functionality details for Watchdog Timers
2026-01-12 feat(wdt): add Task Watchdog Timer (TWDT) implementation for HAL driver to make references for self-built driver
2026-01-12 docs(code-note): expand driver design guidelines with layered architecture and best practices
2026-01-13 feat(hal_drv, lib_clk_def/hal): add HAL driver for references & rename lib to match standards
2026-01-27 feat(sample, lib): restructure lib and sample of HAL driver
2026-02-12 docs(code-note, to-do): enhance driver writing guidelines and update project roadmap
2026-02-13 feat(docs): update driver writing notes and add rationale for using ESP-IDF framework from docs branch
2026-02-13 feat(main): implement reset reason handling and power management configuration
    [main.c]
2026-02-13 docs(to-do): update driver utilization strategy from bare-metal to ESP-IDF
2026-02-19 docs(pcm1808-note): add PCM1808 note with introduction, data format, sampling frequency, and PCB design details
2026-02-19 feat(main): refactor reset handling and power management setup for clarity
    [main.c]
2026-02-25 feat(kicad): add schematics design of main project & update gitignore
    [designspace.kicad_pcb, designspace.kicad_sch]
2026-02-27 feat(kicad): add resitor to stabilize 2.5V data output
    [designspace.kicad_sch]
2026-02-27 docs(ref, sys-des): add reference paper to project for comparison & system design note
2026-02-27 feat(i2s): update I2S standard configuration for 96kHz sample rate and external clock source
2026-03-05 docs(references): add ESP32-S3 series datasheet for reference
2026-03-05 docs(pin-layout): add esp32-s3 pin layout
2026-03-12 feat(main): enhance reset reason logging and update I2S configuration
    [main.c]
2026-03-12 feat(main): remove unused power management configuration and add note on menuconfig usage
2026-03-19 feat(main): refactor app_main to use helper functions for reset reason and CPU clock checks
    [main.c]
2026-04-04 feat(kicad): finalize sch version with jb-313b & max9812
    [designspace.kicad_sch]
2026-04-06 feat(sch): add TCT40-16R support line & redirect signal line to PCM1808
    [designspace.kicad_sch]
2026-04-06 feat(sch): split sch into hier-sch to simplified sch
    [designspace.kicad_sch, designspace_backup.kicad_sch, designspace_max9812.kicad_sch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]
2026-04-09 feat(sch): remove hierachical structure and add import footprint
    [designspace.kicad_sch, designspace_max9812.kicad_sch, designspace_pj313b.kicad_sch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]
2026-04-14 feat(pcb): resolve footprint errors and implement routing between pcm1808, max9812, tct4016r, pj342s
    [designspace.kicad_pcb, designspace.kicad_sch]
2026-04-17 feat(pcb): add kit footprint for esp32 & inital placing
    [designspace.kicad_pcb, designspace.kicad_sch]
2026-04-18 feat(pcb): add routing to pj342s, max9812, tct4016r
    [designspace.kicad_pcb, freerouting.dsn, temp-freerouting.dsn]
2026-04-21 feat(pcb): add ground planning to hide ground tracks
    [designspace.kicad_pcb]
2026-04-28 feat(pcb): add 3 hole pin for MAX9812 complete board
    [designspace.kicad_pcb]
2026-04-28 feat(pcb): increase track size for power line & redirect 5V power line to 74HCU04 & PCM1808
    [designspace.kicad_pcb, designspace.kicad_sch]
2026-05-02 feat(pcb): import pin socket for voltage divider source 12->12/5/3.3, prepared for final validation to pcb manufacturing
    [designspace.kicad_pcb, designspace.kicad_sch]
2026-05-02 feat(gerber): export gerber filer to prepare for pcb manufacturing
    [designspace-B_Courtyard.gbr, designspace-B_Cu.gbr, designspace-B_Fab.gbr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]
2026-05-16 feat(pcb): add round corner & adjust size for actual components
    [designspace.kicad_pcb, designspace.kicad_sch]
2026-05-20 feat(pcb): adjust routing for pcm1808 & update version
    [designspace.kicad_pcb]
2026-05-20 feat(lib, sample): remove sample code, lib & add new server_main source code for interacting with server
